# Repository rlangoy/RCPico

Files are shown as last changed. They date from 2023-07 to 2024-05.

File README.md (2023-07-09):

# Raspbery Pi Pico W RC car
 WIFI RC Car controller using RPI Pico W <br>
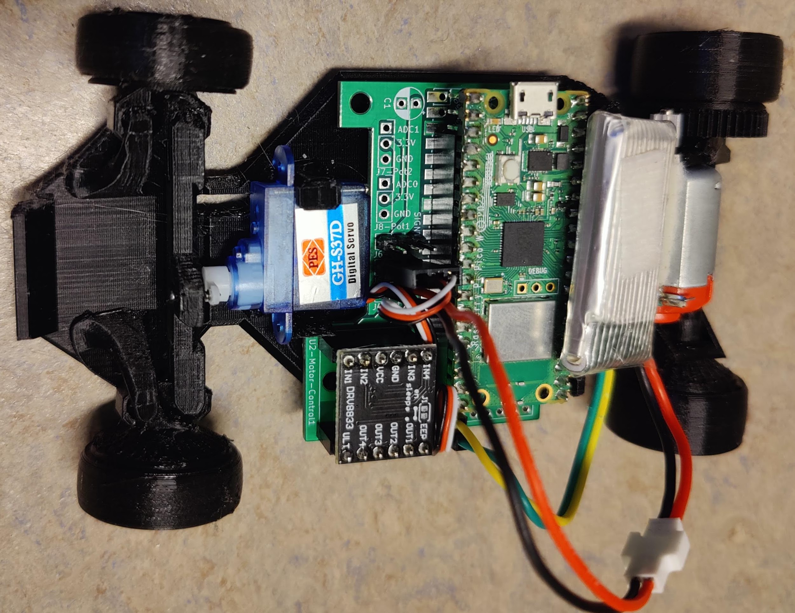
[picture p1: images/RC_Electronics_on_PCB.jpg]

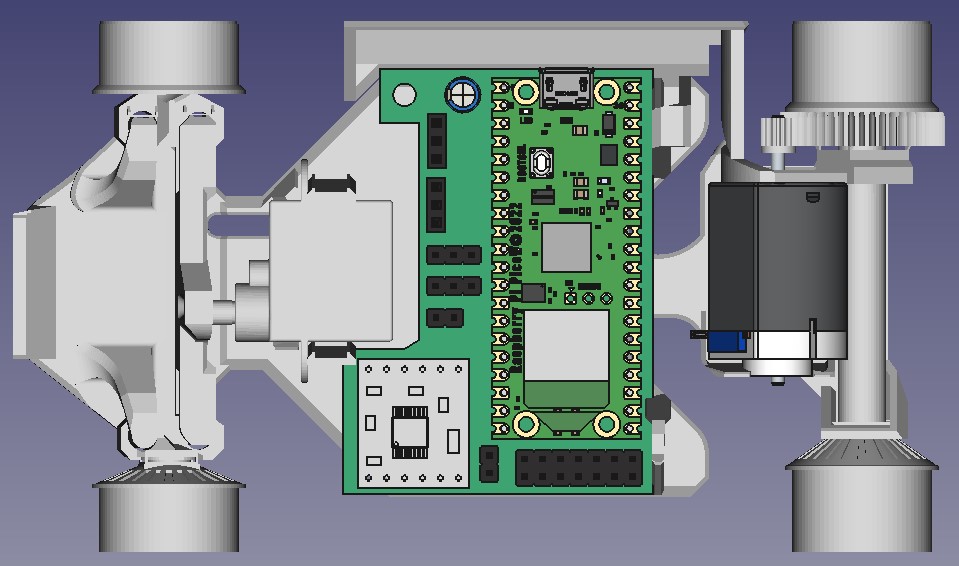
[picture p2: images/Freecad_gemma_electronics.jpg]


The car can be controlled using an web-browser on a mobilephone or PC using  WIFI <br>
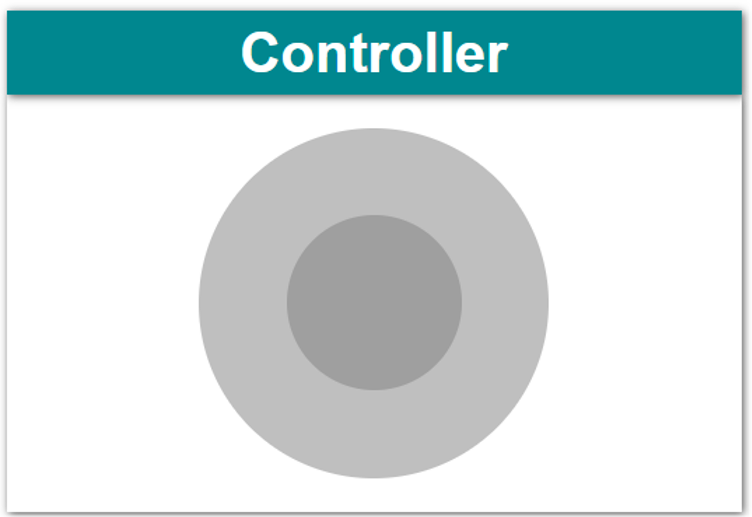
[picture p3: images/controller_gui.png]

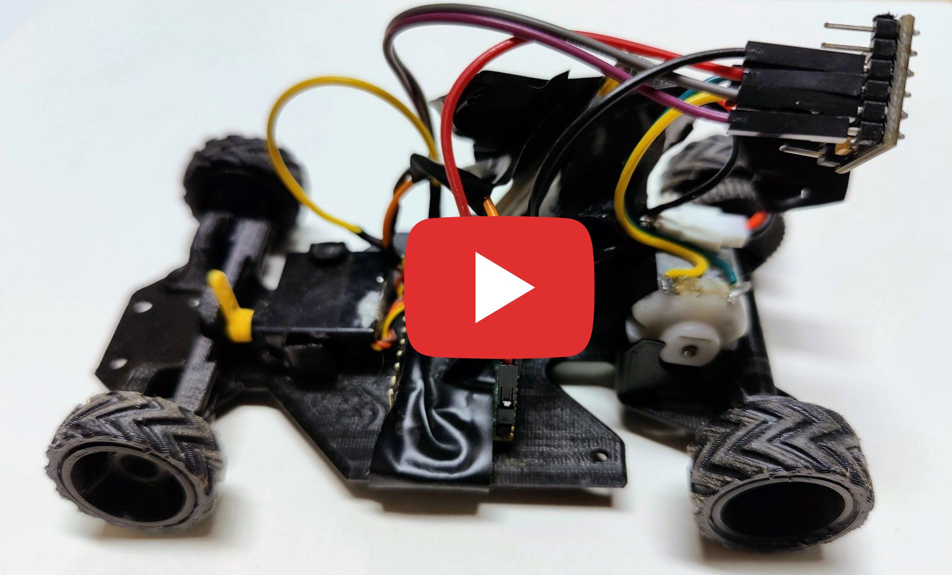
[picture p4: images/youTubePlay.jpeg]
IMAGE ALT TEXT

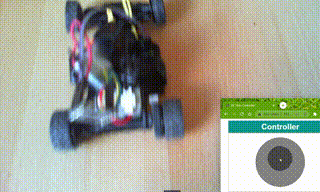
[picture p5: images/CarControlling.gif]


There is no need for a PCB, just connect the hardware compenents using wires acording to the [schematics](KicadV7#rp2040-pinout)

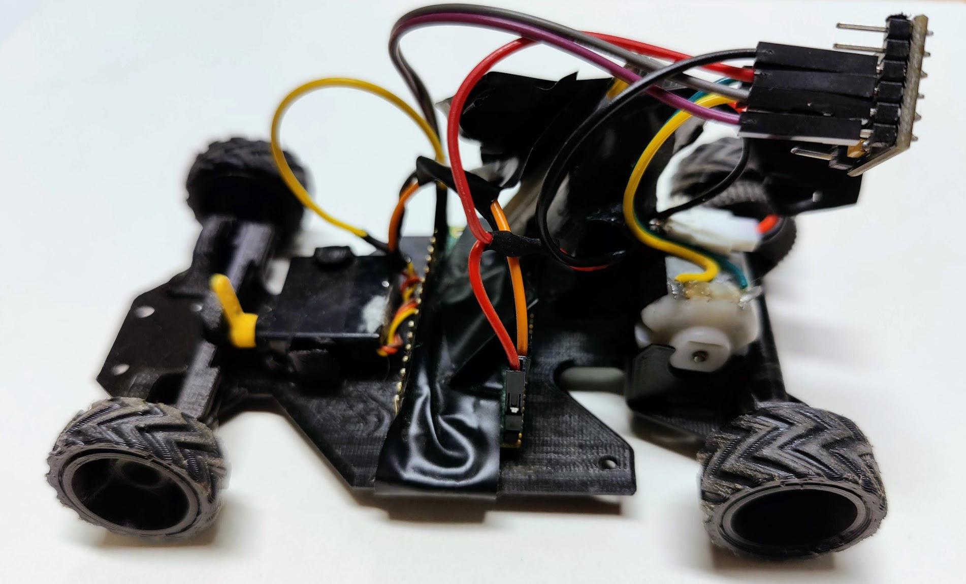
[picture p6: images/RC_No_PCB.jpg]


To cleanup the wires the project includes a PCB-boarddesign  for the 3D printed car [Gamma 2.0](https://cults3d.com/en/3d-model/gadget/gamma-2-demo) <br>

## Project Content 

### KicadV7  
PCB Design files for [Kicadv7](https://www.kicad.org/) \
&nbsp; More Hardware info is available in the [README](/KicadV7/README.md) 

# Software
The software is developed using [MicroPython](https://micropython.org/) \
&nbsp;  on a [Raspberry Pi Pico W](https://www.raspberrypi.com/products/raspberry-pi-pico/) <br>
&nbsp; More Info in the [README](/MicroPython/WifiController/README.md) 

## Instalation
### Firmware 
Download [RCPico.zip](https://github.com/rlangoy/RCPico/releases/download/v1.0/RCPico.zip) <br>

Unzip RCPico.zip <br>
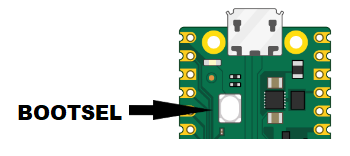
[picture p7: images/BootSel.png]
 <br>
On the microcontroller, press the BOOTSEL button and hold it while you connect the USB cable to your computer <br>
&nbsp; A new drive would appear <br>
Copy the file RCPico.uf2 to the new drive <br>

## Conneting to the car
Scan the QRcode to connect to the car's wifi-network 

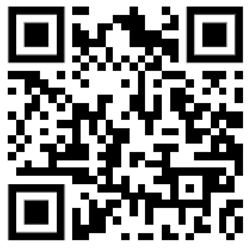
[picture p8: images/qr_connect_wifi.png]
 
This conect you to the car-wifi with ssid = 'GemmmaRC#01' and password = '123456789'

Scann the QRcode to connect to the car's controller/joystock

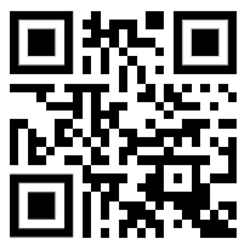
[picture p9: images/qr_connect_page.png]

Open the web-page 192.168.4.1 and now you are ready :)

# 3dr Party resources
## Hardware
For a harrdware list see the [Bil of materials](KicadV7#bil-of-materials-bom) :)

## Software compoenents
[microdot - Micropython web framework](https://github.com/miguelgrinberg/microdot) <br>
[nipplejs - JoyStick JavaScript](https://github.com/yoannmoinet/nipplejs)
## Software tools
[picotool](https://github.com/raspberrypi/picotool) used to grenerate the firmware-file (RCPico.u2f)  <br>
&nbsp; (picotool save -a -f RCPPico.uf2) <br>
# License

<br />This work is licensed under a <a rel="license" href="http://creativecommons.org/licenses/by/4.0/">Creative Commons Attribution 4.0 International License</a>.

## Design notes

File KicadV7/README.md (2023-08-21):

# Kicad Files for the RCPico
### NB  Work in progress things might nor work widt selected components..
## PCB Layout. 
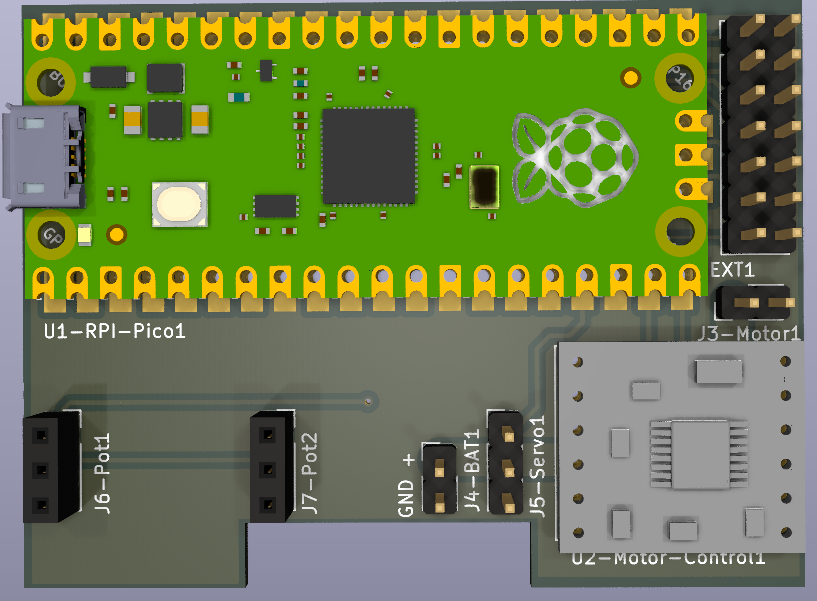
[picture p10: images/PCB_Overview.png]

U2 DRV8833 motor controller needs to be soldered upside down as shown in the photo below 
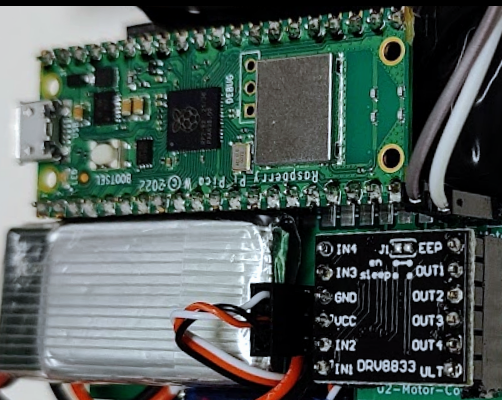
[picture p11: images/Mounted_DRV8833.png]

 
## RP2040 Pinout 
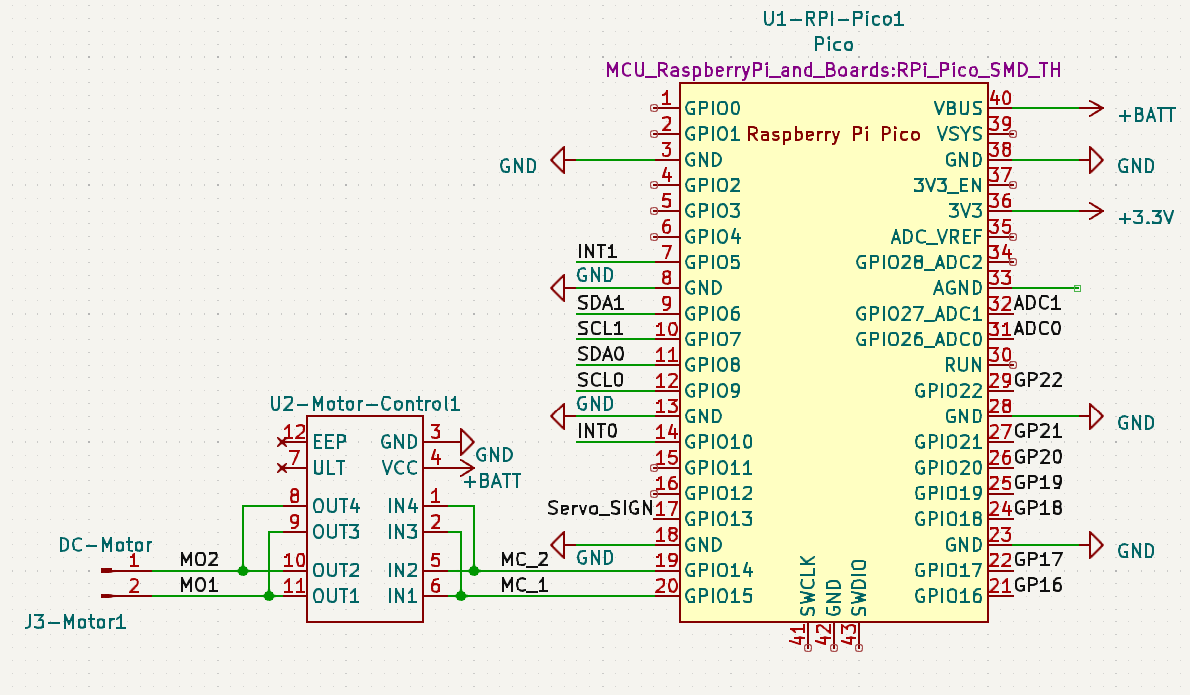
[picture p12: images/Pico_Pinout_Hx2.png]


## Connections

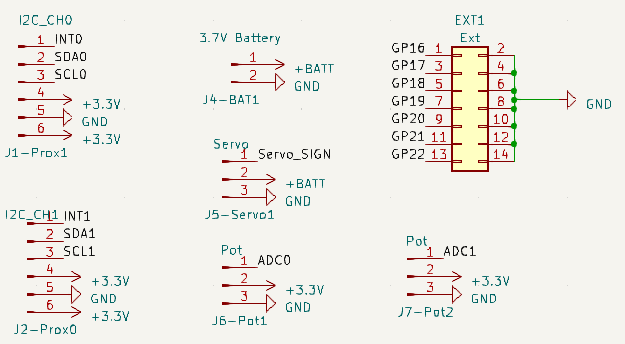
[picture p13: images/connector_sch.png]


## Bil of Materials (BOM)
### PCB

| Quantity | Ref | Prod no | Description | URL |
|---|---|---|---|---|
| 1 | U1 | Rasbperry Pi Pico W | Microcontroller with wifi |  [Farnell](https://no.farnell.com/raspberry-pi/raspberry-pi-pico-w/raspberry-pi-board-arm-cortex/dp/3996082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) |
| 1 | U2 | 1005001633854429 | DRV8833 Motor Driver Module | [Aliexpress](https://www.aliexpress.com/item/1005001633854429.html)  |
| 2 | J1-J2 | 1005005522977746 | 6 pin socket 2.54mm | [Aliexpress](https://www.aliexpress.com/item/1005005522977746.html)  |
| 1 | J3 | 1005004843759392 | 2 pin header 2.54mm | [Aliexpress](https://www.aliexpress.com/item/1005004843759392.html)  |
| 1 | J4 | 32880456356 | Connector XH 2.0mm | [Aliexpress](https://www.aliexpress.com/item/32880456356.html) |
| 3 | J5-J7 | 1005005522977746 | 3 pin Socket 2.54mm | [Aliexpress](https://www.aliexpress.com/item/1005005522977746.html)  |
| 1 | EXT1  | 1005004123467947 | 2x7 Header 2.54mm | [Aliexpress](https://www.aliexpress.com/item/1005004123467947.html)  |
| 1 |  M1 | | 130 DC Motor |  |
| 1 |  M2 | 1005003137639801 | GH-S37D Servo | [Aliexpress](https://www.aliexpress.com/item/1005003137639801.html)  |
| 1 |  BT1  | 1005001859207575 | 3.7V 400mAh Lipo | [Aliexpress](https://www.aliexpress.com/item/1005001859207575.html)  |

Not recommended..  130 DC Motor 1005005481288051  [Aliexpress](https://www.aliexpress.com/item/1005005481288051.html) 
### Other Hardware 

| Quantity | Ref | Prod no | Description | URL |
|---|---|---|---|---|
| 1 |  NA | 1005001623293545 | 0.5M 8-Teeth Pinion 1.95mm |  [Aliexpress](https://www.aliexpress.com/item/1005001623293545.html) |
| 1 | PCB | PCB00 | PCB Production files (gerber) |  [Gerber files](https://github.com/rlangoy/RCPico/raw/main/KicadV7/gerber/gemma20Pico.zip "Gerber files")
| 1 | CAR | GAMMA20 | PIP 3D printed Car |  [Gamma 2.0](https://cults3d.com/en/3d-model/gadget/gamma-2-demo) |

### Optional Hardware for autonomus steering

| Quantity | Ref | Prod no | Description | URL |
|---|---|---|---|---|
| 2 |  NA | 32708290585 |  APDS-9900 |  [Aliexpress](https://www.aliexpress.com/item/32708290585.html) |

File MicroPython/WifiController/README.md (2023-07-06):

# WIFI Remote Controller

Place the finger on the dot to controll the car :)

## Installation

Download [RCPico.zip](https://github.com/rlangoy/RCPico/releases/download/v1.0/RCPico.zip) <br>

Unzip RCPico.zip <br>
 <br>
On the microcontroller, press the BOOTSEL button and hold it while you connect the USB cable to your computer <br>
&nbsp; A new drive would appear <br>
Copy the file RCPico.uf2 to the new drive <br>

### Conneting to the car
Scan the QRcode to connect to the car's wifi-network 

 
This conect you to the car-wifi with ssid = 'GemmmaRC#01' and password = '123456789'

Scann the QRcode to connect to the car's controller/joystock


Open the web-page 192.168.4.1 and now you are ready :)

## Details
The Server side is buildt around two parts:
### Basic file server
  Uses [microdot (a web framework)](https://github.com/miguelgrinberg/microdot) to provide web-client files located in the ./static folder. <br>
  The root request ( / ) forwards the ./static/index.html pages that locads the userinterface as show in the picture below  
  
### Remote Control
  The [joystick (nipplejs)](https://github.com/yoannmoinet/nipplejs) in the web-client reads the position from the controller and forwards to the microcontroller as a
  WebSocket("ws://192.168.1.4/ws") message  where the positionis formated as a [JSON](https://json.org/) string.<br>
  &nbsp; WebScoket Remote control format :
  &nbsp;&nbsp; { "xPos":  xxx , "yPos" : yyy }  <br> 
  &nbsp;&nbsp;&nbsp;&nbsp; xxx - is an integer from -1024 to 1024 ( turning left / right ) <br>
  &nbsp;&nbsp;&nbsp;&nbsp; yyy - is an integer from -1024 to 1024 ( motor speed ) <br>

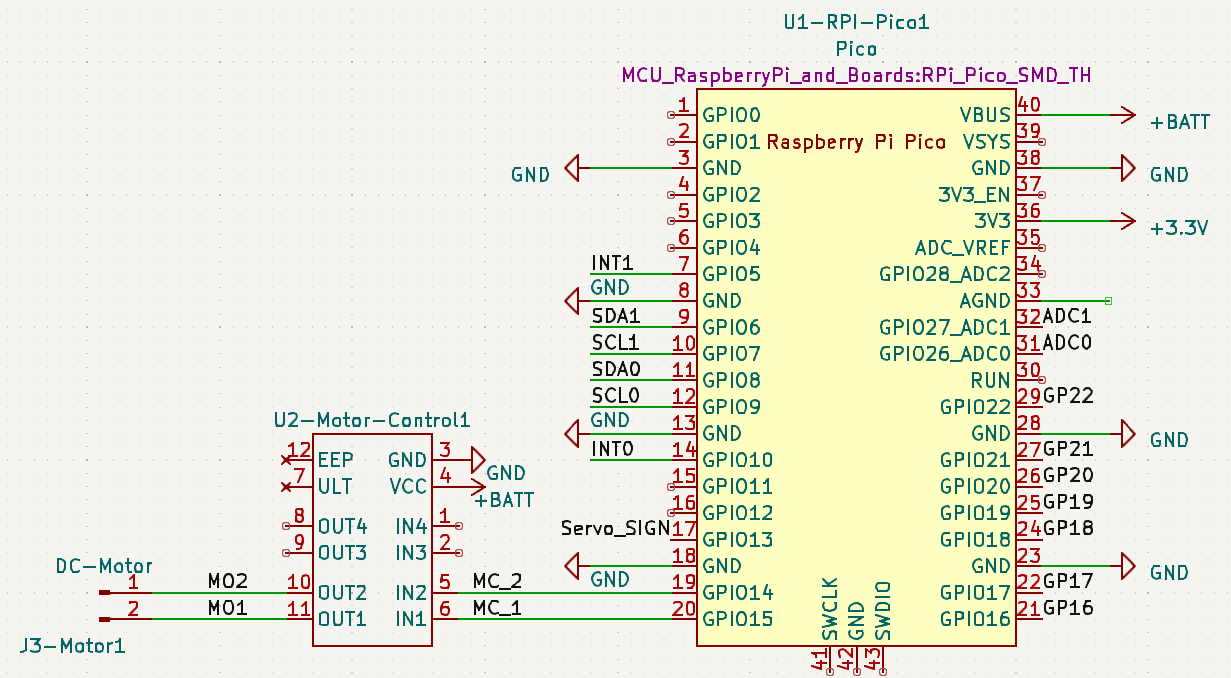
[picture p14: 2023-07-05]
images/Pico_Pinout.png

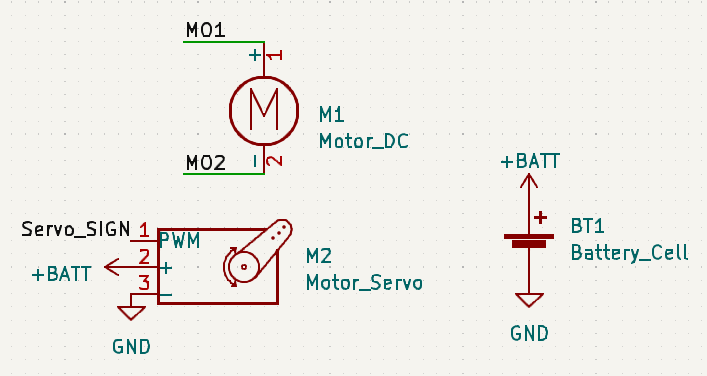
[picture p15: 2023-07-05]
images/sch_ext_comp.png

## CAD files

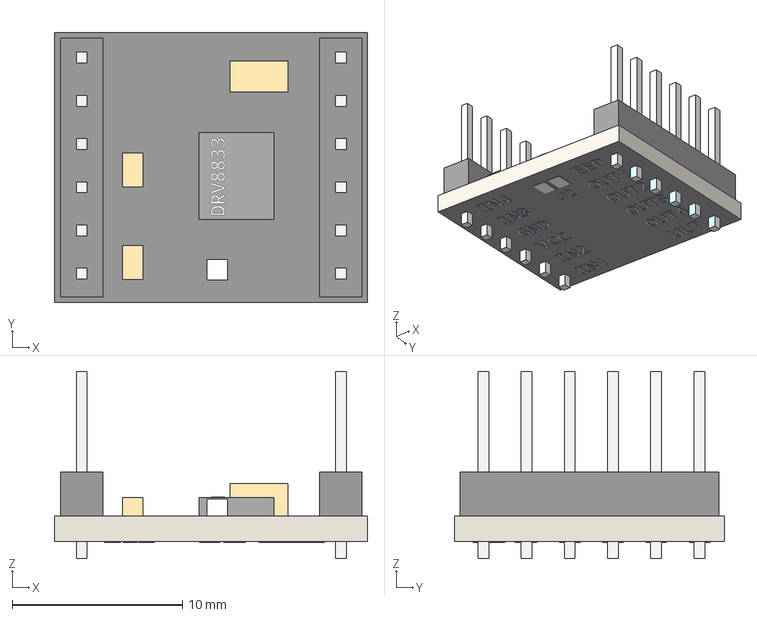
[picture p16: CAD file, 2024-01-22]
3D_Model/HBridgeDRV8833.step
18.4 x 15.9 x 11.0 mm

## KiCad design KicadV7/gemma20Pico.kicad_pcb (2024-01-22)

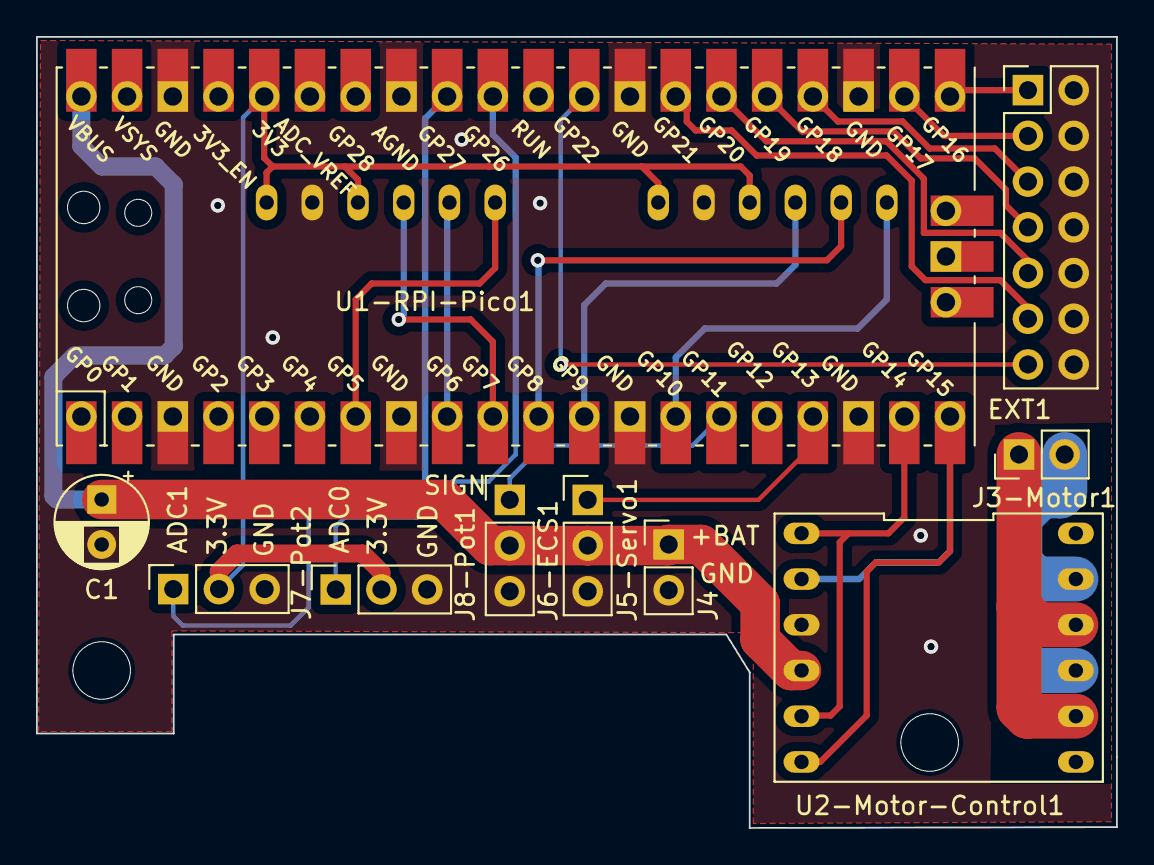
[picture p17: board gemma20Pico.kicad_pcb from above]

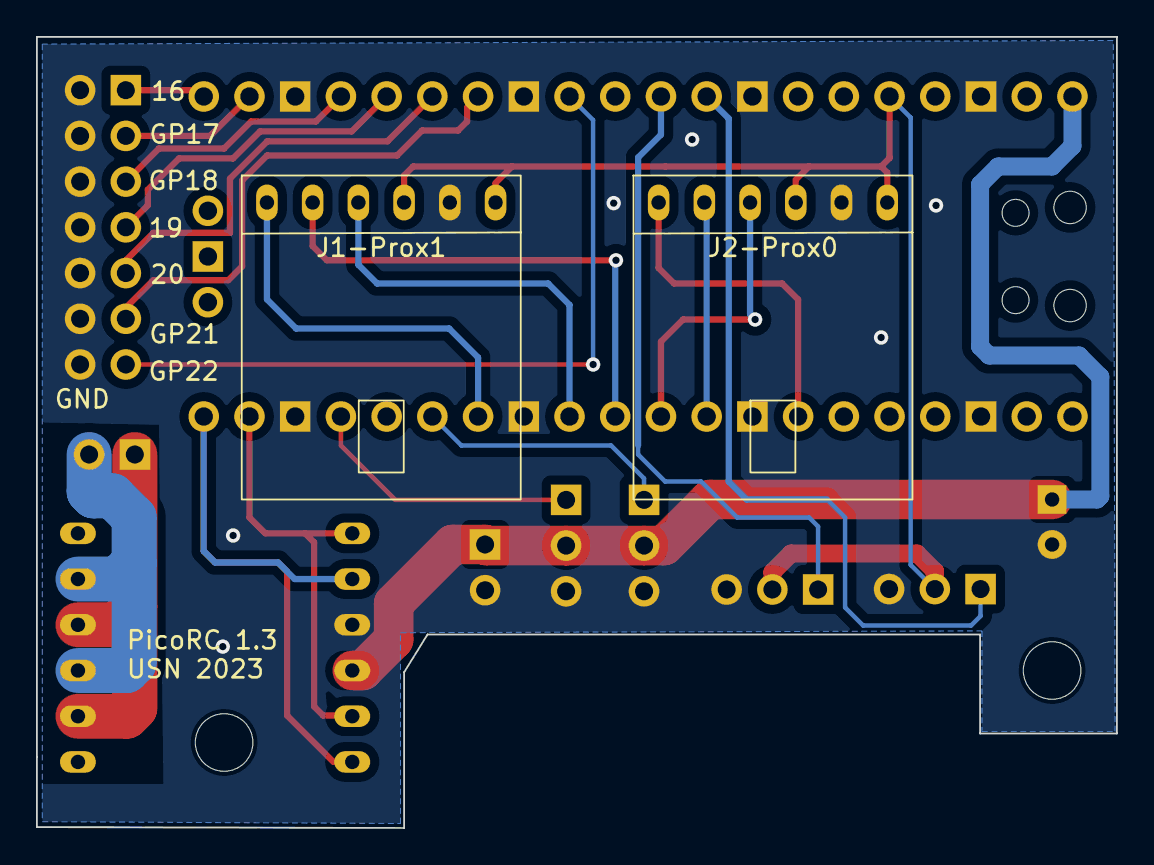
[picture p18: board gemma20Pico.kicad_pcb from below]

Board: 2 copper layers, 60.0 x 44.0 mm, 12 parts (2 on the bottom side), 24 nets.

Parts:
C1: C_Polarized_Small_US; CP_Radial_D5.0mm_P2.50mm
EXT1: Ext; PinHeader_2x07_P2.54mm_Vertical
J1-Prox1: I2C_CH0; SIP-6
J2-Prox0: I2C_CH1; SIP-6
J3-Motor1: DC-Motor; PinHeader_1x02_P2.54mm_Vertical
J4: 3.7V Battery; PinHeader_1x02_P2.54mm_Vertical
J5-Servo1: Servo; PinHeader_1x03_P2.54mm_Vertical
J6-ECS1: ECS/Servo; PinHeader_1x03_P2.54mm_Vertical
J7-Pot2, J8-Pot1: Pot; PinSocket_1x03_P2.54mm_Vertical
U1-RPI-Pico1: Pico; RPi_Pico_SMD_TH
U2-Motor-Control1: DIP-12_600_ELL

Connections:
+3.3V: J1-Prox1.4, J1-Prox1.6, J2-Prox0.4, J2-Prox0.6, J7-Pot2.2, J8-Pot1.2, U1-RPI-Pico1.36 (3V3)
+BATT: C1.1, J4.1, J5-Servo1.2, J6-ECS1.2, U1-RPI-Pico1.40 (VBUS), U2-Motor-Control1.4 (VCC)
/ADC0: J8-Pot1.1, U1-RPI-Pico1.31 (GPIO26_ADC0)
/ADC1: J7-Pot2.1, U1-RPI-Pico1.32 (GPIO27_ADC1)
/ECS_SIGN: J6-ECS1.1, U1-RPI-Pico1.15 (GPIO11)
/GP16: EXT1.1, U1-RPI-Pico1.21 (GPIO16)
/GP17: EXT1.3, U1-RPI-Pico1.22 (GPIO17)
/GP18: EXT1.5, U1-RPI-Pico1.24 (GPIO18)
/GP19: EXT1.7, U1-RPI-Pico1.25 (GPIO19)
/GP20: EXT1.9, U1-RPI-Pico1.26 (GPIO20)
/GP21: EXT1.11, U1-RPI-Pico1.27 (GPIO21)
/GP22: EXT1.13, U1-RPI-Pico1.29 (GPIO22)
/INT0: J1-Prox1.1, U1-RPI-Pico1.14 (GPIO10)
/INT1: J2-Prox0.1, U1-RPI-Pico1.7 (GPIO5)
/MC_1: U1-RPI-Pico1.20 (GPIO15), U2-Motor-Control1.2 (IN3), U2-Motor-Control1.6 (IN1)
/MC_2: U1-RPI-Pico1.19 (GPIO14), U2-Motor-Control1.1 (IN4), U2-Motor-Control1.5 (IN2)
/MO1: J3-Motor1.2, U2-Motor-Control1.9 (OUT3), U2-Motor-Control1.11 (OUT1)
/MO2: J3-Motor1.1, U2-Motor-Control1.8 (OUT4), U2-Motor-Control1.10 (OUT2)
/SCL0: J1-Prox1.3, U1-RPI-Pico1.12 (GPIO9)
/SCL1: J2-Prox0.3, U1-RPI-Pico1.10 (GPIO7)
/SDA0: J1-Prox1.2, U1-RPI-Pico1.11 (GPIO8)
/SDA1: J2-Prox0.2, U1-RPI-Pico1.9 (GPIO6)
/Servo_SIGN: J5-Servo1.1, U1-RPI-Pico1.17 (GPIO13)
GND: C1.2, EXT1.2, EXT1.4, EXT1.6, EXT1.8, EXT1.10, EXT1.12, EXT1.14, J1-Prox1.5, J2-Prox0.5, J4.2, J5-Servo1.3, J6-ECS1.3, J7-Pot2.3, J8-Pot1.3, U1-RPI-Pico1.3 (GND), U1-RPI-Pico1.8 (GND), U1-RPI-Pico1.13 (GND), U1-RPI-Pico1.18 (GND), U1-RPI-Pico1.23 (GND), U1-RPI-Pico1.28 (GND), U1-RPI-Pico1.33 (AGND), U1-RPI-Pico1.38 (GND), U2-Motor-Control1.3 (GND)

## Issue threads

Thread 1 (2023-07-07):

U2,J1,J1 is mirrored

rlangoy, 2023-07-07:
In the PCB  the layout of U2 (motor controller) is mirrored, where the controller needs to be soldered to the back side-
and J1-J2 Prox needs to be mirroerd

rlangoy, 2023-07-07:
Wil Fix in ver 1,1

rlangoy, 2023-08-16:
No need to fix only solder the pins upside/down

Closed 2023-08-16.

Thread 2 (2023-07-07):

Connect the H-bridges in the  DRV8833module  in parallel for double the current

rlangoy, 2023-07-07:
This would  allow to double the output current.
Quick fix is manual connect it like this :

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

rlangoy, 2023-08-16:
Fixed in ver 1.2

Closed 2023-08-16.

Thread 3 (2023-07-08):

DC Motors seems to burn-out when using double H-bridge configuration

rlangoy, 2023-07-08:
Increase Moror PWM Speed to avoid motor heat-buildup ?

rlangoy, 2023-08-16:
Ensure that extra suport is removed and the car is oiled see  [The Gamma 2.0 Build Guide](https://www.youtube.com/watch?v=X2ae7fGiUiQ)

Closed 2023-08-16.

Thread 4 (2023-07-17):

Add ESC Brushless Motor Speed Controller connector

rlangoy, 2023-07-17:
Add ESC Brushless Motor Speed Controller connection  https://www.aliexpress.com/item/1000005040945.html.
Supplyes the board with +5V and speed regulated using PWM

rlangoy, 2023-08-24:
Fixed in ver 1.2

Closed 2023-08-24.

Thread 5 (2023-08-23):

Mirror APDS9900 Sensor

rlangoy, 2023-08-23:
The Proximity sensor APSA9900 Needs to be mirrored

rlangoy, 2023-08-24:
In PBC Editor update the footprint to fix issue

rlangoy, 2023-08-24:
Fixed in V1.3

Closed 2023-08-24.

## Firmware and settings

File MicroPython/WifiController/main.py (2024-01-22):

from microdot_asyncio import Microdot, Response, send_file,redirect
from microdot_asyncio_websocket import with_websocket
from machine import Pin,PWM
import json
import uasyncio
import asyncio
import socket
import os

import time
import network
wlan = network.WLAN(network.STA_IF) # create station interface
SERVER_IP='192.168.4.1'

print(wlan.ifconfig()  )
# Initialize MicroDot
app = Microdot()
#Response.default_content_type = 'text/html'
### Motor
MotorPinIN1=Pin(14,Pin.OUT)
MotorPinIN2=Pin(15,Pin.OUT)
MotorPinIN1.off()   #off- forward on -Backword

MotorSpeed=PWM(Pin(15,Pin.OUT))
MotorSpeed.freq(400)
MotorSpeed.duty_u16(00000)

##
servo=PWM(Pin(13))
servo.freq(50)

#params for:
# HD-1440A
#servoPosMid=2500
#servoPosMax=servoPosMid+700
#servoPosMin=servoPosMid-700  #Mid

# GH-S37D
#servoPosMid=4512
#servoPosMax=7000
#servoPosMin=2024  
servoPosMid=4700
servoPosMax=6800
servoPosMin=2600

config = {
  "servoPosMid": servoPosMid,
  "servoPosMax": servoPosMax,
  "servoPosMin": servoPosMin
}

#Configuration File
configFile= 'config.json'

#If file exists read it if not create it with defailt values
if configFile in os.listdir(): 
    f = open(configFile, 'r')
    js=json.loads(f.read())
    servoPosMid=js['servoPosMid']
    servoPosMax=js['servoPosMax']
    servoPosMin=js['servoPosMin']
    f.close()
else:
    f = open(configFile, 'w')
    f.write(json.dumps(config))
    f.flush()
    f.close()


range_steps=(servoPosMax-servoPosMid)/1024.0

servo.duty_u16(servoPosMid)


led = machine.Pin("LED", machine.Pin.OUT)
led.off()                 # set pin to "on" (high) level


# root route
@app.get('/')
def index(request):
    return send_file('/static/index.html')

@app.get('/hotspot-detect.html')
def apple_captive(request):
     #return redirect('/')
     return '<!DOCTYPE HTML><HTML><HEAD><TITLE>Success</TITLE></HEAD><BODY>Success</BODY></HTML>', 200

@app.errorhandler(404)
def not_found(request):
    #return {'error': 'resource not found'}, 404
    #print(request)
    return send_file('/static/index.html')
    

#The socket needs flow-control if not the input buffer wil be flooded
#The web-client must wait for reply before sending more data
@app.route('/ws')
@with_websocket
async def ws(request, ws):
    c = 0
    old_x_position = 9999
    old_y_position = 9999
    led.on()
    servo.duty_u16(servoPosMid)               # sservoPosMid=2500
    print("------------------  WS Connect -----------------")
    while True:
        data = await ws.receive()
        if(type(data) is str) :
            #print(data)
            jsonRecievedData=json.loads(data)
            xPos=jsonRecievedData['xPos']    # Get the xPos element fro the JSON dataobj
            yPos=jsonRecievedData['yPos']    # Get the xPos element fro the JSON dataobj
            
            if(type(xPos) is int) :         #check if data is a int (recieved properly)                   
               #print(f"xPos {xPos}") # Debug data
               if(old_x_position != xPos):
                   old_x_position = xPos
                   turnWheel(xPos)        #Move steering-wheels

            if(type(yPos) is int) :         #check if data is a int (recieved properly)                   
               #print(f"yPos {yPos}") # Debug data
               if(old_y_position != yPos):
                   old_y_position = yPos
                   motorSpeed(yPos)
               
            data = '{}_{}'.format(data, 'ack')        # Echo response
            await ws.send(data)          # send ack to recieve more data

# Static CSS/JSS
@app.route("/static/<path:path>")
def static(request, path):
    if ".." in path:
        # directory traversal is not allowed
        return "Not found", 404
    #print(path)
    return send_file("static/" + path)

#Turn the car to the left/right
#valid numbers is from -1024 to +1024

def turnWheel(position) :
    
    servo_position=servoPosMid+int(range_steps*position)
       
    #print(f"Input pos: {position}, Servo Pos  {servo_position} ")
    #servo.init(freq = 50, duty = 512)
    servo.duty_u16(servo_position)
    #time.sleep(.05)
    
    #servoRangeMax=6800
    #servoRangeMin=4700
#     servoZeroservoPosMid=servoRangeMin+int((servoRangeMax-servoRangeMin)/2)
#     normPos=position/-1023.0 # Pos is normalized (from -1.0 to +1.0)
#     
#     servoPos= servoZero + int(((servoRangeMax-servoRangeMin)/2)*normPos)
    position=servoPosMid+position
    if(position<servoPosMin) :
         position=servoPosMin
    if(position>servoPosMax) :
         position=servoPosMax

     #servoPosMid=2500
     #servoPosMax=servoRangeMid+1000
     #servoPosMin=servoRangeMid-1000  #Mid

    #print(normPos,servoPos)
    #servo.duty_u16(position)
    

#valid numbers is from -1024 to +1024
def motorSpeed(speed) :
    #set forward speed
    speedNormalized=speed/1024
    if(speed>0):
        if(speed>1.0):
          speed=1.0
        MotorPinIN1.off()   #off- forward motion 
        MotorSpeed.duty_u16(int(speedNormalized*65535))
    else :
        #MotorSpeed.duty_u16(0)
        MotorPinIN1.on()   #reverse motion
        sp=65535+int(speedNormalized*65535)
        #print(sp)
        MotorSpeed.duty_u16(sp)
        



# shutdown
@app.get('/shutdown')
def shutdown(request):
    request.app.shutdown()
    led.off()
    servo.deinit()
    return 'The server is shutting down...'



class DNSQuery:
	def __init__(self, data):
		self.data = data
		self.domain = ''
		tipo = (data[2] >> 3) & 15  # Opcode bits
		if tipo == 0:  # Standard query
			ini = 12
			lon = data[ini]
			while lon != 0:
				self.domain += data[ini + 1:ini + lon + 1].decode('utf-8') + '.'
				ini += lon + 1
				lon = data[ini]
		#print("searched domain:" + self.domain)

	def response(self, ip):

		#print("Response {} == {}".format(self.domain, ip))
		if self.domain:
			packet = self.data[:2] + b'\x81\x80'
			packet += self.data[4:6] + self.data[4:6] + b'\x00\x00\x00\x00'  # Questions and Answers Counts
			packet += self.data[12:]  # Original Domain Name Question
			packet += b'\xC0\x0C'  # Pointer to domain name
			packet += b'\x00\x01\x00\x01\x00\x00\x00\x3C\x00\x04'  # Response type, ttl and resource data length -> 4 bytes
			packet += bytes(map(int, ip.split('.')))  # 4bytes of IP
		#print(packet)
		return packet

# function to handle incoming dns requests
async def run_dns_server():

    udps = socket.socket(socket.AF_INET, socket.SOCK_DGRAM)

    # set non-blocking otherwise execution will stop at 'recvfrom' until a connection is received
    #  and this will prevent the other async threads from running
    udps.setblocking(False)

    # bind to port 53 on all interfaces
    udps.bind(('0.0.0.0', 53))

    while True:
        try:
            gc.collect()

            data, addr = udps.recvfrom(4096)
            #print("Incoming data...")

            DNS = DNSQuery(data)
            udps.sendto(DNS.response(SERVER_IP), addr)

            #print("Replying: {:s} -> {:s}".format(DNS.domain, SERVER_IP))

            await asyncio.sleep_ms(10)

        except Exception as e:
            #print("Timeout")
            await asyncio.sleep_ms(10000)

    udps.close()


if __name__ == "__main__":
    try:
        #run_dns_server()
        #r=uasyncio.create_task(run_dns_server())
        #app.run(port=80,debug=False)
        loop = asyncio.get_event_loop()
        loop.create_task(run_dns_server())
        loop.create_task(app.run(port=80,debug=False))
        loop.run_forever()
        loop.close()
        
    except KeyboardInterrupt:
        pass

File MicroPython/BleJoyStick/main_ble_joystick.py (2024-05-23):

# This example finds and connects to a peripheral running the
# UART service (e.g. ble_simple_peripheral.py).

# This example demonstrates the low-level bluetooth module. For most
# applications, we recommend using the higher-level aioble library which takes
# care of all IRQ handling and connection management. See
# https://github.com/micropython/micropython-lib/tree/master/micropython/bluetooth/aioble

import bluetooth
import random
import struct
import time
import json
import micropython
from machine import Pin,PWM
from ble_advertising import decode_services, decode_name

from micropython import const

_IRQ_CENTRAL_CONNECT = const(1)
_IRQ_CENTRAL_DISCONNECT = const(2)
_IRQ_GATTS_WRITE = const(3)
_IRQ_GATTS_READ_REQUEST = const(4)
_IRQ_SCAN_RESULT = const(5)
_IRQ_SCAN_DONE = const(6)
_IRQ_PERIPHERAL_CONNECT = const(7)
_IRQ_PERIPHERAL_DISCONNECT = const(8)
_IRQ_GATTC_SERVICE_RESULT = const(9)
_IRQ_GATTC_SERVICE_DONE = const(10)
_IRQ_GATTC_CHARACTERISTIC_RESULT = const(11)
_IRQ_GATTC_CHARACTERISTIC_DONE = const(12)
_IRQ_GATTC_DESCRIPTOR_RESULT = const(13)
_IRQ_GATTC_DESCRIPTOR_DONE = const(14)
_IRQ_GATTC_READ_RESULT = const(15)
_IRQ_GATTC_READ_DONE = const(16)
_IRQ_GATTC_WRITE_DONE = const(17)
_IRQ_GATTC_NOTIFY = const(18)
_IRQ_GATTC_INDICATE = const(19)

_ADV_IND = const(0x00)
_ADV_DIRECT_IND = const(0x01)
_ADV_SCAN_IND = const(0x02)
_ADV_NONCONN_IND = const(0x03)

_UART_SERVICE_UUID = bluetooth.UUID("6E400001-B5A3-F393-E0A9-E50E24DCCA9E")
_UART_RX_CHAR_UUID = bluetooth.UUID("6E400002-B5A3-F393-E0A9-E50E24DCCA9E")
_UART_TX_CHAR_UUID = bluetooth.UUID("6E400003-B5A3-F393-E0A9-E50E24DCCA9E")

led = machine.Pin("LED", machine.Pin.OUT)
rxString="Empty"

class BLESimpleCentral:
    def __init__(self, ble):
        self._ble = ble
        self._ble.active(True)
        self._ble.irq(self._irq)

        self._reset()

    def _reset(self):
        # Cached name and address from a successful scan.
        self._name = None
        self._addr_type = None
        self._addr = None

        # Callbacks for completion of various operations.
        # These reset back to None after being invoked.
        self._scan_callback = None
        self._conn_callback = None
        self._read_callback = None

        # Persistent callback for when new data is notified from the device.
        self._notify_callback = None

        # Connected device.
        self._conn_handle = None
        self._start_handle = None
        self._end_handle = None
        self._tx_handle = None
        self._rx_handle = None

    def _irq(self, event, data):
        if event == _IRQ_SCAN_RESULT:
            addr_type, addr, adv_type, rssi, adv_data = data
            if adv_type in (_ADV_IND, _ADV_DIRECT_IND) and _UART_SERVICE_UUID in decode_services(
                adv_data
            ):
                # Found a potential device, remember it and stop scanning.
                self._addr_type = addr_type
                self._addr = bytes(
                    addr
                )  # Note: addr buffer is owned by caller so need to copy it.
                self._name = decode_name(adv_data) or "?"
                self._ble.gap_scan(None)

        elif event == _IRQ_SCAN_DONE:
            if self._scan_callback:
                if self._addr:
                    # Found a device during the scan (and the scan was explicitly stopped).
                    self._scan_callback(self._addr_type, self._addr, self._name)
                    self._scan_callback = None
                else:
                    # Scan timed out.
                    self._scan_callback(None, None, None)

        elif event == _IRQ_PERIPHERAL_CONNECT:
            # Connect successful.
            conn_handle, addr_type, addr = data
            if addr_type == self._addr_type and addr == self._addr:
                self._conn_handle = conn_handle
                self._ble.gattc_discover_services(self._conn_handle)

        elif event == _IRQ_PERIPHERAL_DISCONNECT:
            # Disconnect (either initiated by us or the remote end).
            conn_handle, _, _ = data
            if conn_handle == self._conn_handle:
                # If it was initiated by us, it'll already be reset.
                self._reset()

        elif event == _IRQ_GATTC_SERVICE_RESULT:
            # Connected device returned a service.
            conn_handle, start_handle, end_handle, uuid = data
            print("service", data)
            if conn_handle == self._conn_handle and uuid == _UART_SERVICE_UUID:
                self._start_handle, self._end_handle = start_handle, end_handle

        elif event == _IRQ_GATTC_SERVICE_DONE:
            # Service query complete.
            if self._start_handle and self._end_handle:
                self._ble.gattc_discover_characteristics(
                    self._conn_handle, self._start_handle, self._end_handle
                )
            else:
                print("Failed to find uart service.")

        elif event == _IRQ_GATTC_CHARACTERISTIC_RESULT:
            # Connected device returned a characteristic.
            conn_handle, def_handle, value_handle, properties, uuid = data
            if conn_handle == self._conn_handle and uuid == _UART_RX_CHAR_UUID:
                self._rx_handle = value_handle
            if conn_handle == self._conn_handle and uuid == _UART_TX_CHAR_UUID:
                self._tx_handle = value_handle

        elif event == _IRQ_GATTC_CHARACTERISTIC_DONE:
            # Characteristic query complete.
            if self._tx_handle is not None and self._rx_handle is not None:
                # We've finished connecting and discovering device, fire the connect callback.
                if self._conn_callback:
                    self._conn_callback()
            else:
                print("Failed to find uart rx characteristic.")

        elif event == _IRQ_GATTC_WRITE_DONE:
            conn_handle, value_handle, status = data
            print("TX complete")

        elif event == _IRQ_GATTC_NOTIFY:
            conn_handle, value_handle, notify_data = data
            if conn_handle == self._conn_handle and value_handle == self._tx_handle:
                if self._notify_callback:
                    self._notify_callback(notify_data)

    # Returns true if we've successfully connected and discovered characteristics.
    def is_connected(self):
        return (
            self._conn_handle is not None
            and self._tx_handle is not None
            and self._rx_handle is not None
        )

    # Find a device advertising the environmental sensor service.
    def scan(self, callback=None):
        self._addr_type = None
        self._addr = None
        self._scan_callback = callback
        self._ble.gap_scan(2000, 30000, 30000)
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

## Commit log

2023-07-03 Update index.html
    Title changed to RC Pico Controller
2023-07-03 Controll montion and steering
2023-07-03 Fix reversed steering
2023-07-03 Cleanup connectors
    [gemma20Pico.kicad_sch]
2023-07-04 Added websocket quing
    if there is a websocket que send only the last msg the othes is droped
2023-07-05 Added External components to the schematics
    [gemma20Pico.kicad_sch]
2023-07-09 Connect H bridges in paralell
    Connect H-Bridges in paralell for 2xcurrent, added mounting holes , reduced board size to allow G9 Servo mount moved and rotated POT for easyer access to +3.3V
    [gemma20Pico.kicad_pcb, gemma20Pico.kicad_sch]
2023-07-11 Calibrates servos for GH-S37D
2023-07-11 Servo pos reversed and reduce motor PWM speed to alow H-Bridge to work
    [main.py]
2023-07-12 Addad title head info
    [gemma20Pico.kicad_sch]
2023-07-12 Added decoupling capacitor for the Pico amd added description
    [gemma20Pico.kicad_sch]
2023-07-17 Added ECS Pins & cleanup
    Added ECS connector allows the DRV8833 to be replaced with brushless motor controller for RC (also provides +5v)
    [gemma20Pico-B_Cu.gbr, gemma20Pico-B_Mask.gbr, gemma20Pico-B_Paste.gbr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]
2023-08-02 Reduced Size to better fir the new gamma2.0
    [gemma20Pico-B_Cu.gbr, gemma20Pico-B_Mask.gbr, gemma20Pico-B_Paste.gbr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]
2023-08-24 Fix Footprit Pox sensors was not updated
    [gemma20Pico-B_Cu.gbr, gemma20Pico-B_Mask.gbr, gemma20Pico-B_Paste.gbr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]
2023-09-26 update servo calibration
    Small update
2023-10-06 Uses Captive portal for ease of connecting
    Redirect DNS request to the microcontroller to avoid specifying the web-site (http://192.168.4.1/)
    [main.py]
2023-10-11 Load servo range variabls from config.json
2023-10-11 fix add lib os
    [main.py]
